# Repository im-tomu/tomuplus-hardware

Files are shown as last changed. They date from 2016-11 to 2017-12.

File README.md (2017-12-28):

# THIS PROJECT HAS BEEN ABANDONED!

The Tomu+ has been abandoned and is not under development.

<br>
<br>
<br>
<br>
<br>
<br>
<br>
<br>
<br>
<br>
<br>
<br>
<br>
<br>
<br>
<br>
<br>
<br>
<br>
<br>
<br>
<br>
<br>
<br>
<br>
<br>
<br>
<br>
<br>
<br>
<br>
<br>
<br>
<br>
<br>
<br>
<br>
<br>
<br>

----

# [Tomu+, I'm](tomu.im)

[I'm Tomu+](tomu.im) a *improved* tiny ARM microprocessor which fits in your USB port.
I have two buttons and two LEDs.

Tomu Front Render
Tomu Back Render

## Contact

 * [Announcement mailing list](https://groups.google.com/forum/#!forum/tomu-announce/join) - Low traffic list for announcements.
 * [Discussion mailing list](https://groups.google.com/forum/#!forum/tomu-discuss/join) - List for discussing development / new features / etc.
 * [IRC Channel - irc://irc.freenode.net/#tomu](https://webchat.freenode.net/?channels=#tomu) - IRC channel for discussing anything related to the project.

## WARNING: This design hasn't been proven yet!

Built out of a 3d printed part + 2 layer "thin" PCB (0.4mm or 0.6mm thick).

The board has;
 * 6mil traces
 * 6mil clearance
 * 0.3mm drill / 0.6mm vias

--

Uses a Freescale Semiconductor / NXP Kinetis KL27 (MKL27Z256VFM4) ([datasheet](http://cache.freescale.com/files/32bit/doc/data_sheet/KL27P64M48SF6.pdf)).

The important features are;
 * [~$5.00 USD on Digikey](https://www.digikey.com.au/product-detail/en/freescale-semiconductor-nxp/MKL27Z256VFM4/MKL27Z256VFM4-ND/4988919)
 * QFN32 - 5mm x 5mm package
 * Inbuilt 5V to 3V3 regulator.
 * Crystal-less USB

These make something which is almost hand solder-able fit into the tiny size.

## BOM

All parts are ordered from Digikey but could easily be ordered from somewhere else.

 * [Digikey BOM in CSV format](bom-digikey.csv)

Individual parts;

 * Resistors
  - 2 x 0402 - 33 Ohm - [Digikey](https://www.digikey.com.au/short/35385r)
  - 2 x 0402 - ~50 Ohm (Depends on LED choice)
  - 1 x 0402 - 10k Ohm

 * Capacitors - [Digikey Capacitors 0402, >1uF](https://www.digikey.com.au/short/3m8r4z)
  - 1 x Capacitor ~2.2uF 0402
  - 1 x Capacitor ~4.7uF 0402

 * 2 x LED 0402
  - You choice of two different colors (might require adjustment of R1/R2).
  - 5mA LEDs are better choice.
  - Get highest millicandela rating you can.
  - [Digikey Search of LEDs in 0402 package](https://www.digikey.com.au/short/3m8rz0)

 * 1 x MKL27Z256VFM4 - [Digikey](https://www.digikey.com.au/short/353852)

 * (Optional) 1 x Atmel ATECC508A Auth IC - [Digikey](https://www.digikey.com.au/short/35385n)

## TODO

 * Create the device
 * Create the 3d print model.
 * Write the firmware for the device.

## FAQ

##### Why did you create this?

The aim was to prove that a device which fits in your USB port could be created
**by hobbists in small quantities** extremely cheaply.

##### Where does the name Tomu come from?

TOMU comes from the abbreviation "Tim's Open Micro USB".

##### What can I use this for?

What ever you want! If you do create something, please send me the info!

## License

The contents of this repository excluding "third_party" folder is released
under your choice of the following two licences:

 * the "Creative Commons Attribution-ShareAlike 4.0 International License"
   (CC BY-SA 4.0) full text of this license is included in the LICENSE file
   and a copy can also be found at
   http://creativecommons.org/licenses/by-sa/4.0/

 * the "TAPR Open Hardware License" full text of this license is included
   in the LICENSE file and a copy can also be found at
   http://www.tapr.org/OHL

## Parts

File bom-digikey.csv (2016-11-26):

Digi-Key Part Number | Manufacturer | Manufacturer Part Number | Customer Reference | Quantity 1 | Quantity 2 | Quantity 3 | Mfg Std Lead Time | Description | Comments | RoHS Status | Lead Free Status | REACH Status
YAG1264CT-ND | YAGEO (VA) | RC0402FR-0733RP | R3 R4 | 2 | 0 | 0 | 22 Weeks | RES SMD 33 OHM 1% 1/16W 0402 | Alternate Packaging Exists | RoHS Compliant | Lead free | Unaffected Dec-2015
478-4596-1-ND | AVX CORPORATION (VA) | 0402ZD105KAT2A | C2 | 2 | 0 | 0 | 8 Weeks | CAP CER 1UF 10V X5R 0402 | Alternate Packaging Exists | RoHS Compliant | Lead free | Unaffected Jun-2016
490-5915-1-ND | MURATA ELECTRONICS (VA) | GRM155R60J475ME47D | C3 | 1 | 0 | 0 | 17 Weeks | CAP CER 4.7UF 6.3V X5R 0402 | Alternate Packaging Exists | RoHS Compliant | Lead free | Unaffected Dec-2015
754-1815-1-ND | KINGBRIGHT COMPANY LLC (VA) | APG1005VGC-T-5MAV | D1 | 1 | 0 | 0 | 8 Weeks | LED GREEN CLEAR 0402 SMD | Alternate Packaging Exists | RoHS Compliant | Lead free | Unaffected Dec-2015
YAG3180CT-ND | YAGEO (VA) | RC0402FR-0752R3L | R1 R2 | 2 | 0 | 0 | 22 Weeks | RES SMD 52.3 OHM 1% 1/16W 0402 | Alternate Packaging Exists | RoHS Compliant | Lead free | Unaffected Dec-2015
LNJ247W82RACT-ND | PANASONIC ELECTRONIC COMPONENTS (VA) | LNJ247W82RA | D2 | 1 | 0 | 0 | 14 Weeks | LED RED 0402 SMD |  | RoHS Compliant | Lead free | Not Available
MKL27Z256VFM4-ND | NXP USA INC | MKL27Z256VFM4 | U1 | 1 | 0 | 0 | 10 Weeks | IC MCU 32BIT 256KB FLASH 32QFN |  | RoHS Compliant | Lead free | Unaffected Dec-2015
ATECC508A-MAHCZ-SCT-ND | ATMEL (VA) | ATECC508A-MAHCZ-S | U2 | 1 | 0 | 0 | 25 Weeks | AUTHENTICATION CHIP SWI 8-UDFN | Backorders not allowed - please contact Digi-Key | RoHS Compliant | Lead free | Not Available
311-10KJRCT-ND | YAGEO (VA) | RC0402JR-0710KL | R5 | 1 | 0 | 0 | 22 Weeks | RES SMD 52.3 OHM 1% 1/16W 0402 | Alternate Packaging Exists | RoHS Compliant | Lead free | Unaffected Dec-2015

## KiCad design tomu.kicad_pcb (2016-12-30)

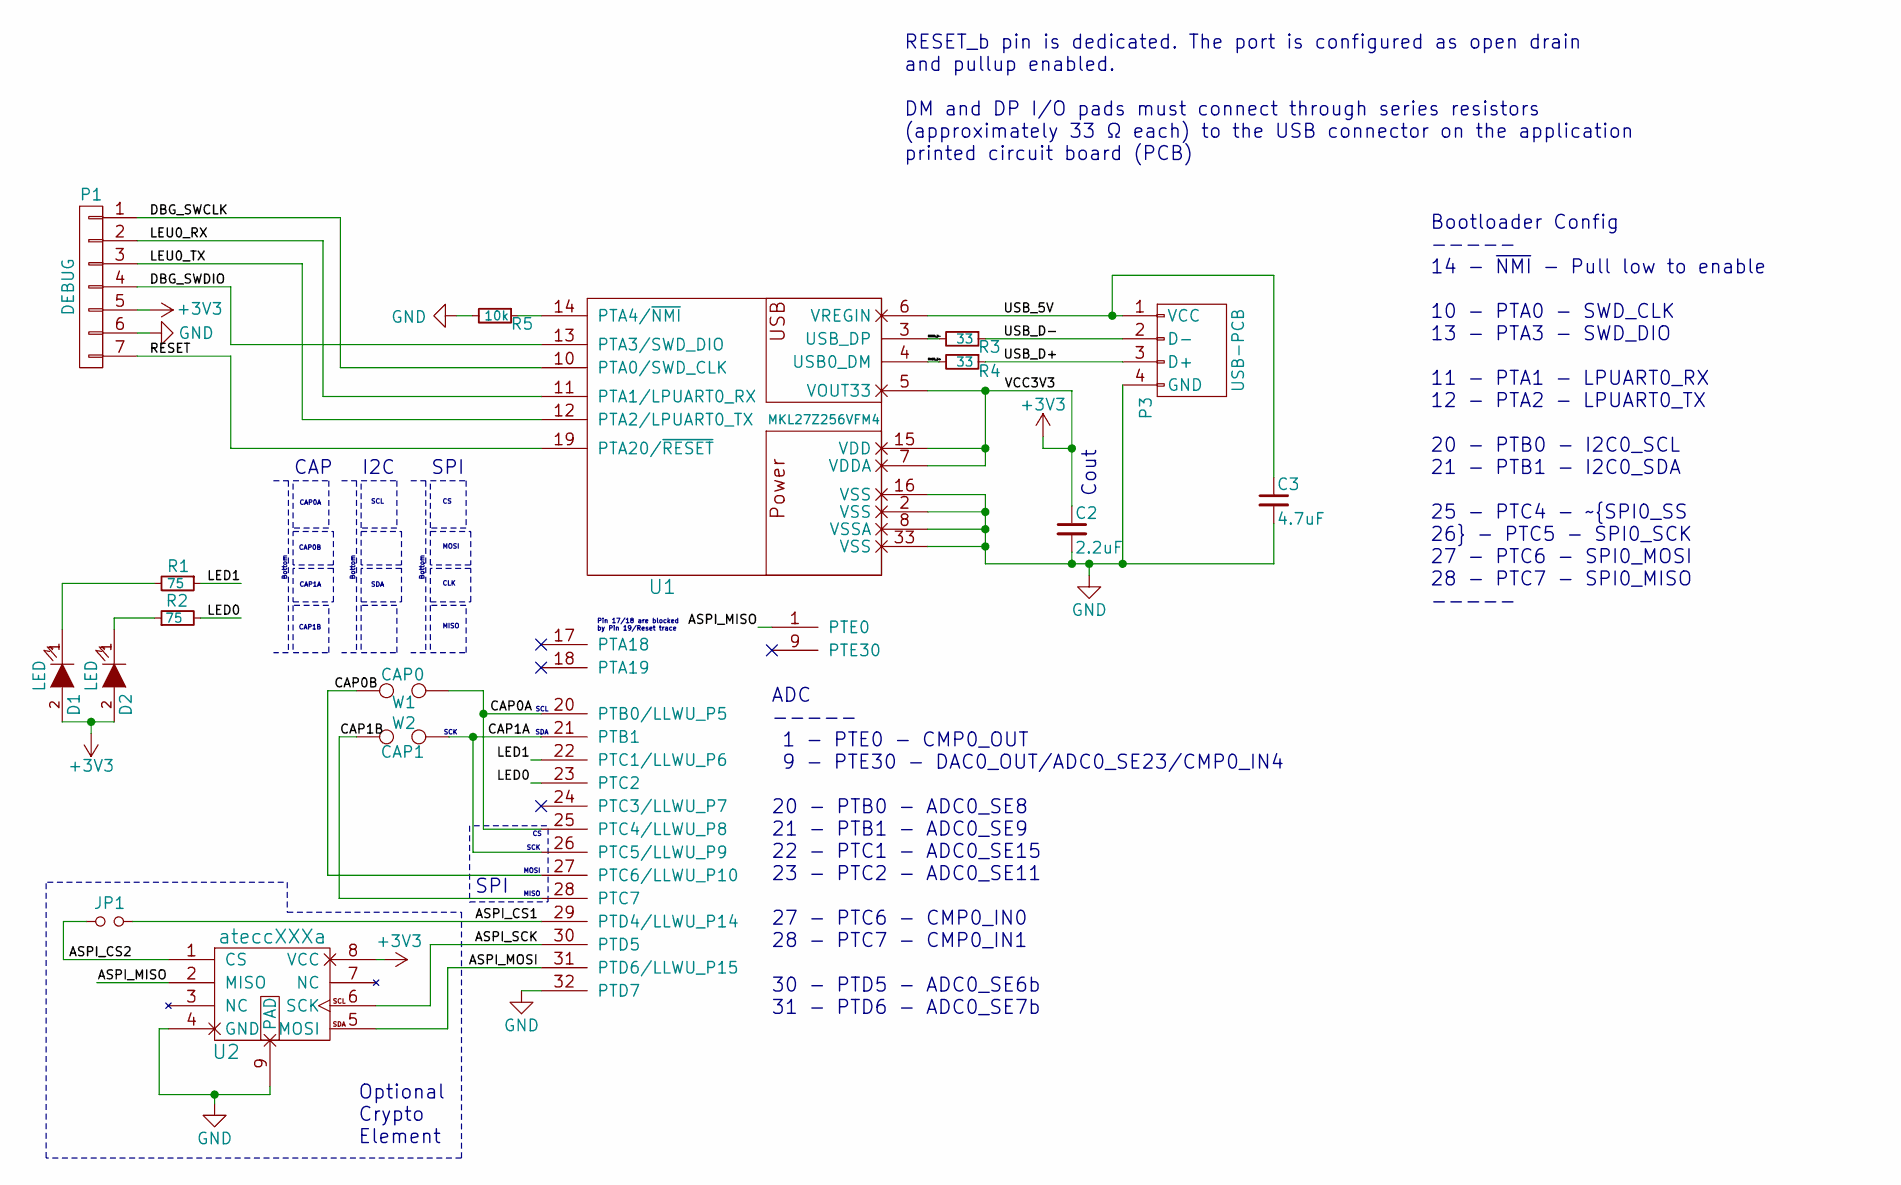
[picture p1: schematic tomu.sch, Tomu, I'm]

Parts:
C2: 2.2uF; C_0402
C3: 4.7uF; C_0402
D1, D2: LED; LED_0402
JP1: Jumper_NO_Small; R_0402
P1: DEBUG; debug-points-127mm
P3: USB-PCB
R1, R2: 75; R_0402
R3, R4: 33; R_0402
R5: 10k; R_0402
U1: MKL27Z256VFM4; QFN-32-1EP_5x5mm_Pitch0.5mm
U2: ateccXXXa; DFN-8-1EP_3x2mm_Pitch0.5mm
W1: CAP0; cap-points
W2: CAP1; cap-points

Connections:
+3V3: C2.1, D1.2 (A), D2.2 (A), P1.5, U1.5 (VOUT33), U1.7 (VDDA), U1.15 (VDD), U2.8 (VCC)
/ASPI_CS1: JP1.2, U1.29 (PTD4/LLWU_P14)
/ASPI_CS2: JP1.1, U2.1 (CS)
/ASPI_MISO: U1.1 (PTE0), U2.2 (MISO)
/ASPI_MOSI: U1.31 (PTD6/LLWU_P15), U2.5 (MOSI)
/ASPI_SCK: U1.30 (PTD5), U2.6 (SCK)
/CAP0A: U1.20 (PTB0/LLWU_P5), U1.25 (PTC4/LLWU_P8), W1.1
/CAP0B: U1.27 (PTC6/LLWU_P10), W1.2
/CAP1A: U1.21 (PTB1), U1.26 (PTC5/LLWU_P9), W2.1
/CAP1B: U1.28 (PTC7), W2.2
/DBG_SWCLK: P1.1, U1.10 (PTA0/SWD_CLK)
/DBG_SWDIO: P1.4, U1.13 (PTA3/SWD_DIO)
/LED0: R2.2, U1.23 (PTC2)
/LED1: R1.1, U1.22 (PTC1/LLWU_P6)
/LEU0_RX: P1.2, U1.11 (PTA1/LPUART0_RX)
/LEU0_TX: P1.3, U1.12 (PTA2/LPUART0_TX)
/RESET: P1.7, U1.19 (PTA20/~RESET)
/RUSB_D+: R4.2, U1.4 (USB0_DM)
/RUSB_D-: R3.2, U1.3 (USB_DP)
/USB_5V: C3.1, P3.1 (VCC), U1.6 (VREGIN)
/USB_D+: P3.3 (D+), R4.1
/USB_D-: P3.2 (D-), R3.1
GND: C2.2, C3.2, P1.6, P3.4 (GND), R5.2, U1.2 (VSS), U1.8 (VSSA), U1.16 (VSS), U1.32 (PTD7), U1.33 (VSS), U2.4 (GND), U2.9 (PAD)
unnamed: D1.1 (K), R1.2
unnamed: D2.1 (K), R2.1
unnamed: R5.1, U1.14 (PTA4/~NMI)

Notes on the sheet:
Bootloader Config ----- 14 - ~NMI~ - Pull low to enable 10 - PTA0 - SWD_CLK 13 - PTA3 - SWD_DIO 11 - PTA1 - LPUART0_RX 12 - PTA2 - LPUART0_TX 20 - PTB0 - I2C0_SCL 21 - PTB1 - I2C0_SDA 25 - PTC4 - ~SPI0_SS 26 - PTC5 - SPI0_SCK 27 - PTC6 - SPI0_MOSI 28 - PTC7 - SPI0_MISO -----
Cout
RESET_b pin is dedicated. The port is configured as open drain and pullup enabled. DM and DP I/O pads must connect through series resistors (approximately 33 Ω each) to the USB connector on the application printed circuit board (PCB)
Pin 17/18 are blocked by Pin 19/Reset trace
ADC ----- 1 - PTE0 - CMP0_OUT 9 - PTE30 - DAC0_OUT/ADC0_SE23/CMP0_IN4 20 - PTB0 - ADC0_SE8 21 - PTB1 - ADC0_SE9 22 - PTC1 - ADC0_SE15 23 - PTC2 - ADC0_SE11 27 - PTC6 - CMP0_IN0 28 - PTC7 - CMP0_IN1 30 - PTD5 - ADC0_SE6b 31 - PTD6 - ADC0_SE7b
SPI
SCK
MOSI
MISO
SCL
SDA
CAP0A
CAP0B
CAP1A
CAP1B
CLK
I2C
CAP
Bottom
Optional Crypto Element

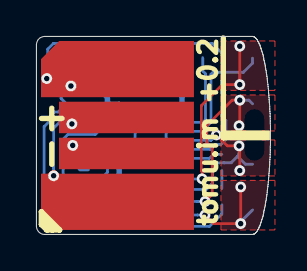
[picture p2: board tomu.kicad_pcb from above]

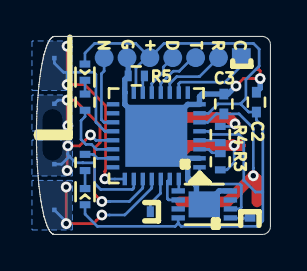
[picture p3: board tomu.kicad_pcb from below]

Board: 2 copper layers, 13.0 x 11.0 mm, 16 parts (15 on the bottom side), 26 nets.

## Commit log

2016-09-10 Slowly making work...
    [tomu.sch]
2016-09-10 Lots of small updates.
    [tomu.sch]
2016-09-12 Getting closer to working.
    [tomu.kicad_pcb, tomu.sch]
2016-11-25 Working on the debug header.
    [tomu.kicad_pcb, tomu.sch]
2016-11-25 More work...
    [tomu.kicad_pcb, tomu.sch]
2016-11-25 Adding atecc508a part.
    [tomu.kicad_pcb, tomu.sch]
2016-11-26 Allow any of the ATECC parts.
    [tomu.sch]
2016-11-26 Temp commit before net import.
    [tomu.kicad_pcb]
2016-11-26 Another temp commit.
    [tomu.kicad_pcb, tomu.sch]
2016-11-26 More improvements.
    [tomu.kicad_pcb, tomu.sch]
2016-11-26 Fully routed design which passes DRC.
    [tomu.kicad_pcb, tomu.sch]
2016-11-26 Making the gnd traces thicker.
    [tomu.kicad_pcb]
2016-11-26 Improving the silkscreen.
    [tomu.kicad_pcb]
2016-11-26 Removing the base Tomu releases from directory.
    [tomu-CuBottom.gbl, tomu-CuTop.gtl, tomu-EdgeCuts.gm1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]
2016-11-26 Setting version to +0.0
    [tomu.kicad_pcb]
2016-11-26 Adding slot.
    [tomu.kicad_pcb]
2016-11-26 Fixing a GND trace.
    [tomu.kicad_pcb]
2016-11-26 Adjust a trace.
    [tomu.kicad_pcb]
2016-11-26 Bumping version to +0.1
    [tomu-CuBottom.gbl, tomu-CuTop.gtl, tomu-EdgeCuts.gm1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]
2016-11-26 Pull the atmel chip in further.
    [tomu.kicad_pcb]
2016-11-26 Bumping version to +0.2
    [tomu-CuBottom.gbl, tomu-CuTop.gtl, tomu-EdgeCuts.gm1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]
2016-11-26 Updating the BOM a little.
    [bom-digikey.csv]
2016-12-29 Closed small gap in Edge.Cuts layer
    Small gap prevented 3D viewer from properly rendering outline
    [tomu.kicad_pcb]

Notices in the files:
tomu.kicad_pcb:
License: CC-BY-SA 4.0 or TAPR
